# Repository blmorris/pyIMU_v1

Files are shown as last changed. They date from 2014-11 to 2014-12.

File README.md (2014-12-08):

pyskin-IMU
==========

Directory pyIMU contains an IMU skin for the pyboard, providing the MPU9150 accelerometer / gyro / magnetometer and the BMP180 barometric altimeter.

The eagle library pyIMU-03.lbr provides all components and symbols used in this board and schematic.

UPDATE: pyIMU-GPS contains an updated version of the original pyIMU board with a fully integrated GPS receiver module and interface circuitry for monitoring current draw and voltage on a Li-polymer battery pack.

Several device packages have been modified from the originals provided by Sparkfun and the standard Eagle libraries; this is to eliminate design rule check errors and ensure that there is soldermask between the pins on the fine-pitch (0.5mm) components.

The project uses the SSC-EAGLE-2Lyr_v1.0.0.3.dru design rule file; this is a design rule set for 2-layer boards provided by Sunstone Circuits: http://www.sunstone.com/news-resources/cad-tools/eagle

The current project should not generate any errors when run against this DRU file.

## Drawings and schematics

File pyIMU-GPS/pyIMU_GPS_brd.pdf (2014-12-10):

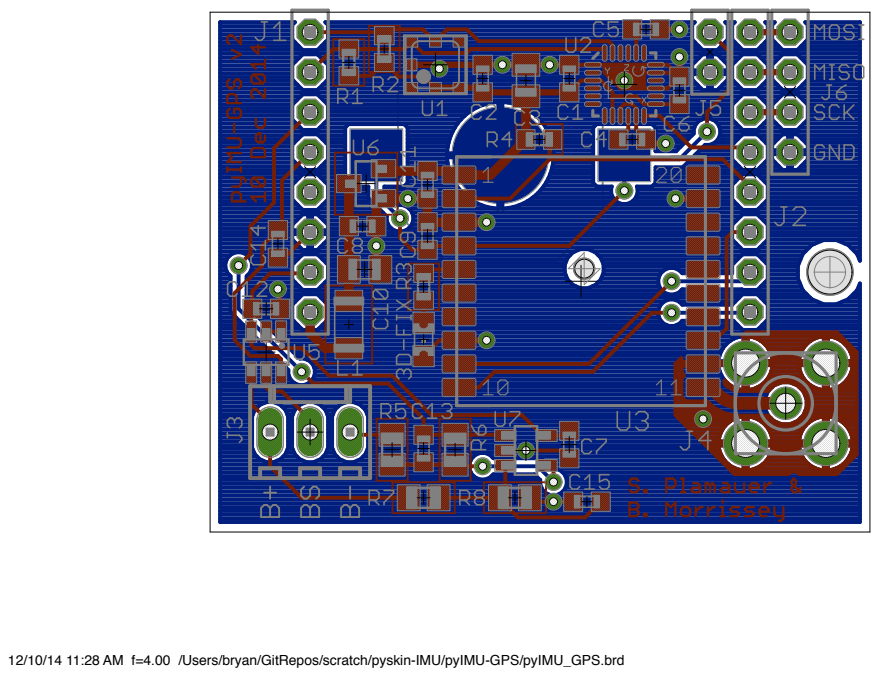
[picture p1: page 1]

12/10/14 11:28 AM f=4.00 /Users/bryan/GitRepos/scratch/pyskin-IMU/pyIMU-GPS/pyIMU_GPS.brd

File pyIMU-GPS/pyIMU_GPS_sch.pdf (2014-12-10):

A

A

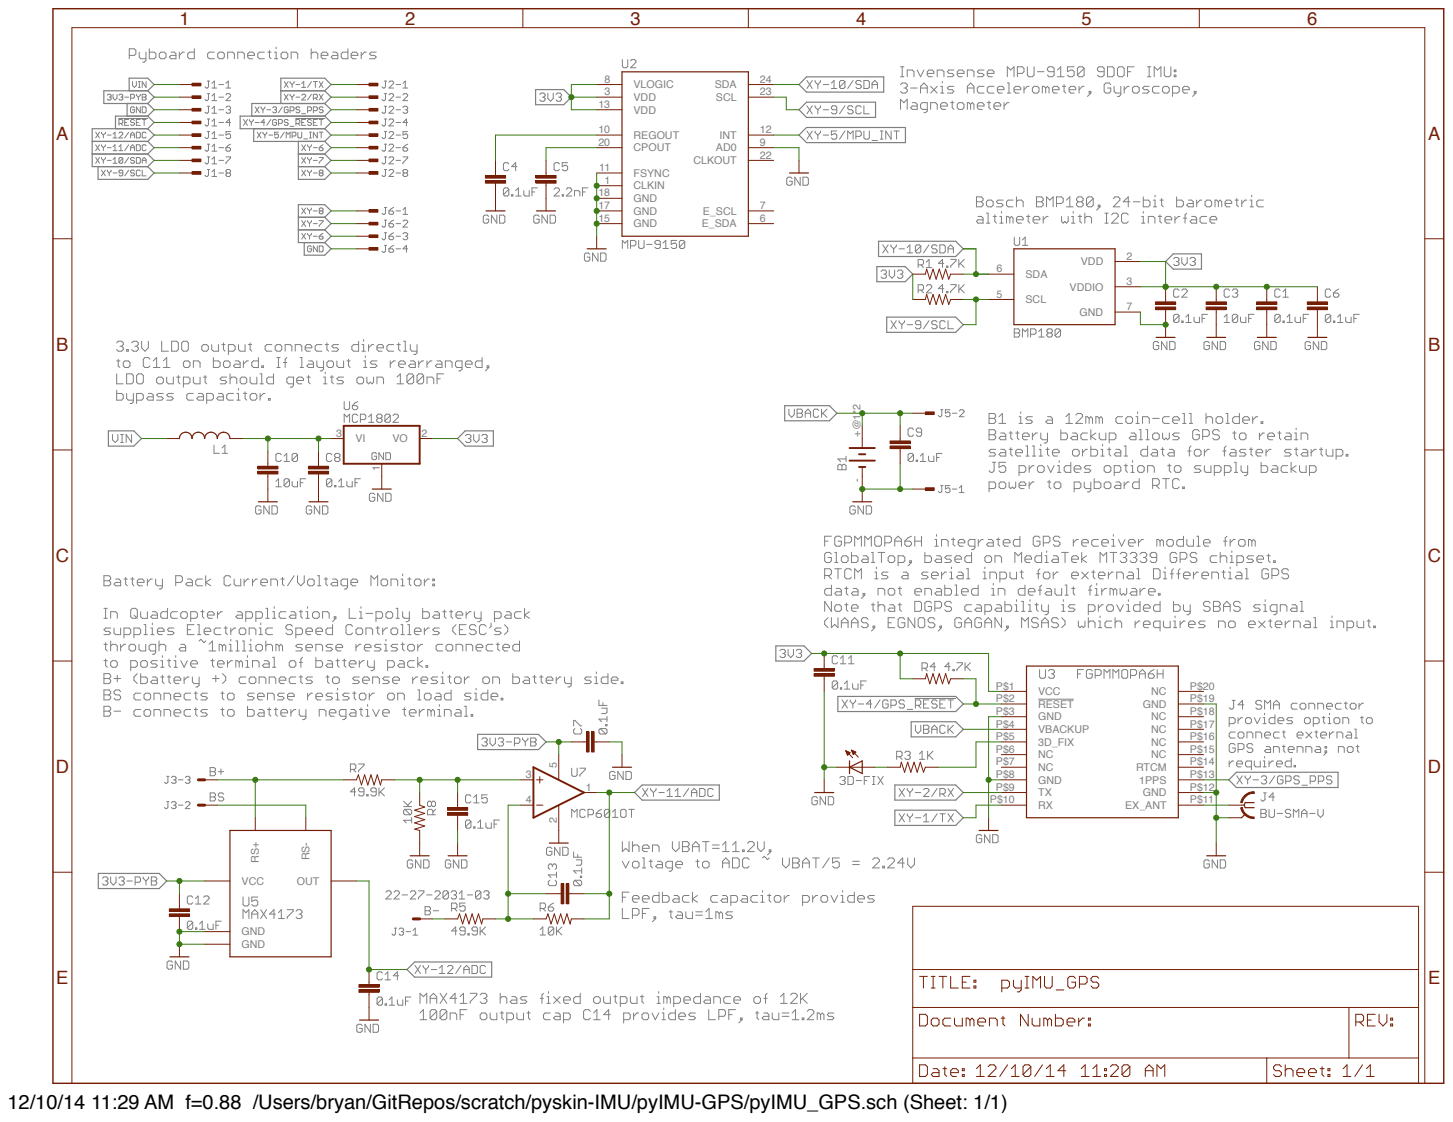
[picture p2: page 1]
GND; 7 SCL 5; SDA 6; VDD; VDDIO; CLKIN 1; CLKOUT; 22 CPOUT 20; E_SCL; E_SDA; FSYNC 11; GND 15; GND 17; GND 18; INT; 12 REGOUT 10; SCL; 23 SDA; VDD 3 VDD 13; VLOGIC 8; RESET P$2; 1PPS; 3D_FIX P$5; EX_ANT; GND P$3; GND P$8; RTCM; VBACKUP P$4; VCC P$1; VCC; OUT

12/10/14 11:29 AM f=0.88 /Users/bryan/GitRepos/scratch/pyskin-IMU/pyIMU-GPS/pyIMU_GPS.sch (Sheet: 1/1)

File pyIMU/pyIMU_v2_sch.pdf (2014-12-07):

1

2

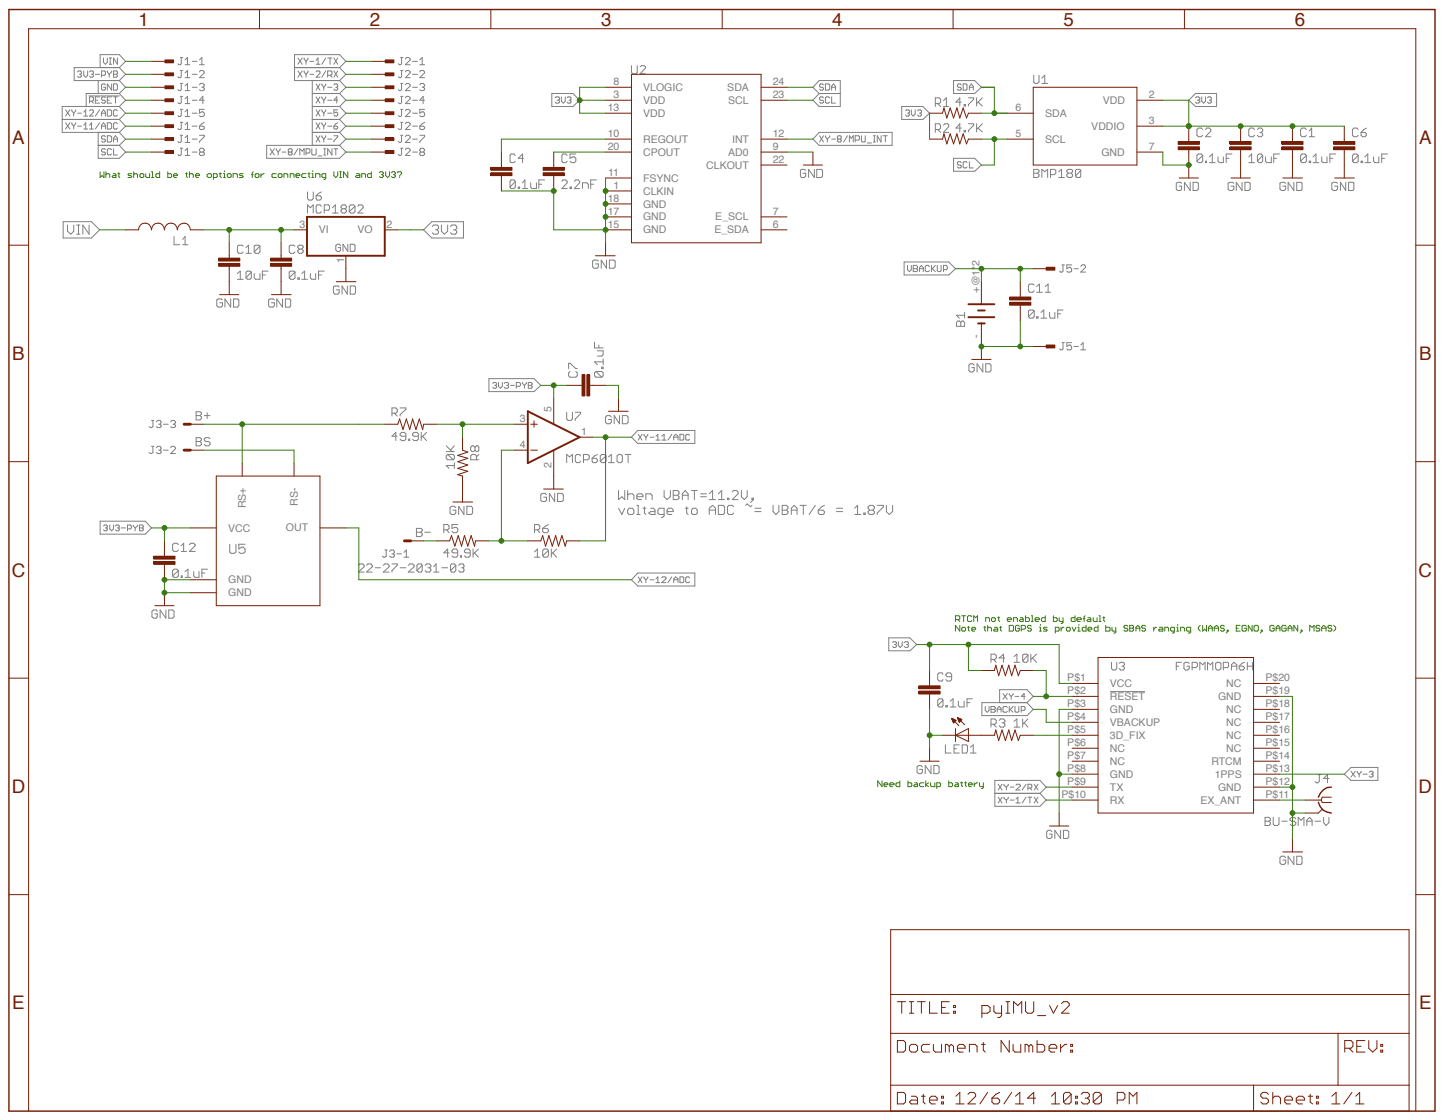
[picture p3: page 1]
GND; 7 SCL; SDA; VDD; VDDIO; CLKIN; CLKOUT; 22 CPOUT 20; E_SCL; E_SDA; FSYNC 11; GND 15; GND 17; GND 18; INT; 12 REGOUT 10; SCL; 23 SDA; 3 VDD 13; VLOGIC; VCC P$1 RESET P$2 GND P$3 VBACKUP P$4 3D_FIX P$5 NC P$6 NC P$7 GND P$8 TX P$9; EX_ANT; P$11 GND; P$12 1PPS; P$13 RTCM; VCC; OUT; ABCDE

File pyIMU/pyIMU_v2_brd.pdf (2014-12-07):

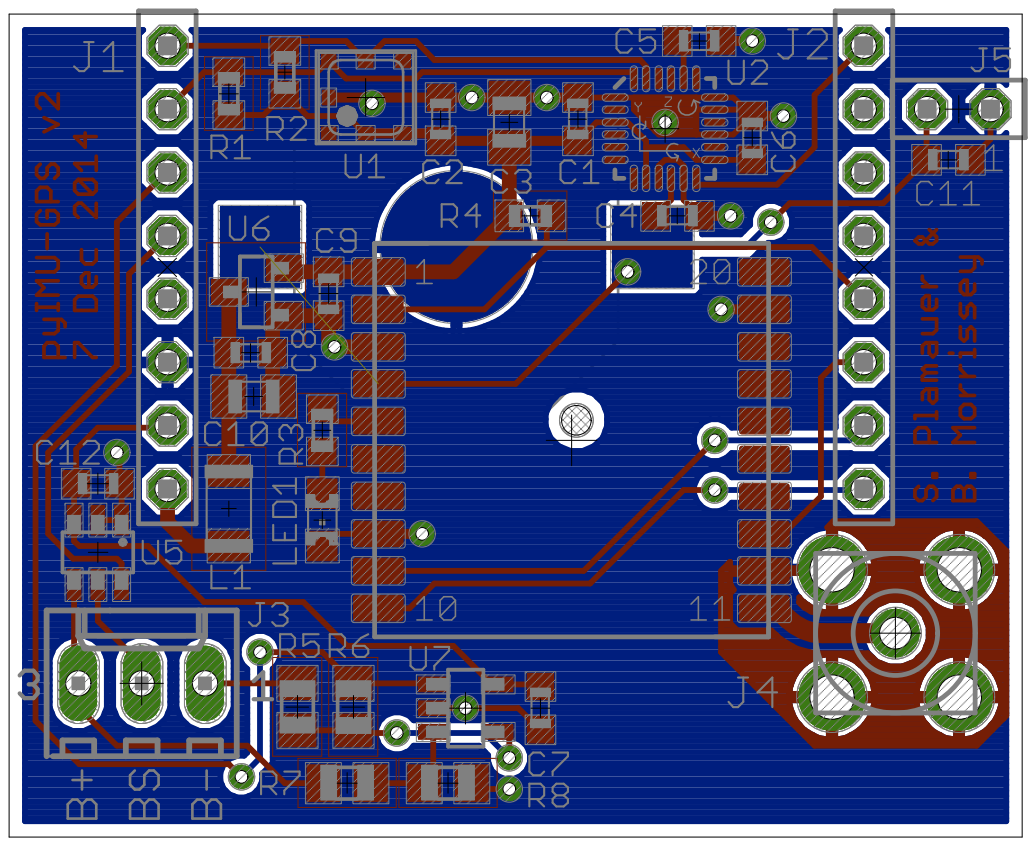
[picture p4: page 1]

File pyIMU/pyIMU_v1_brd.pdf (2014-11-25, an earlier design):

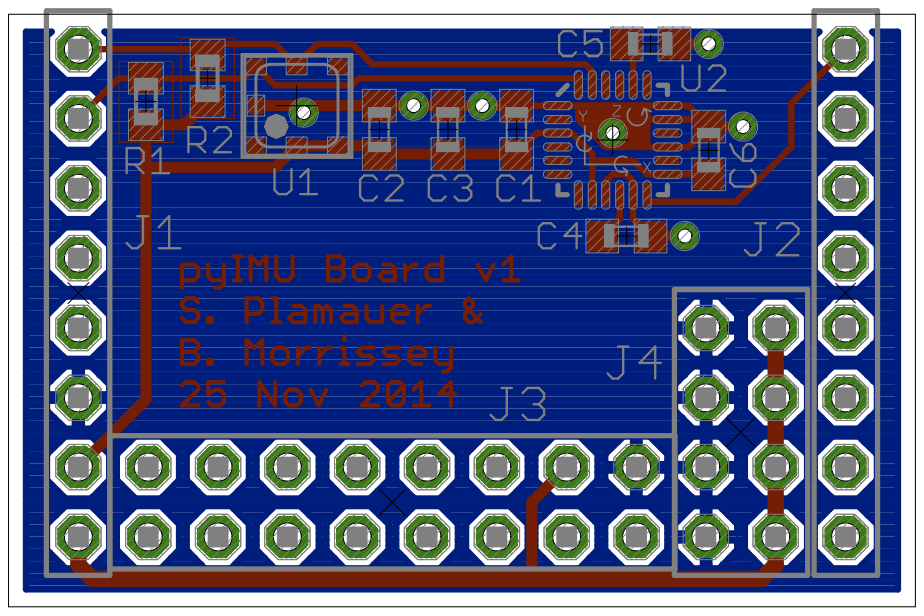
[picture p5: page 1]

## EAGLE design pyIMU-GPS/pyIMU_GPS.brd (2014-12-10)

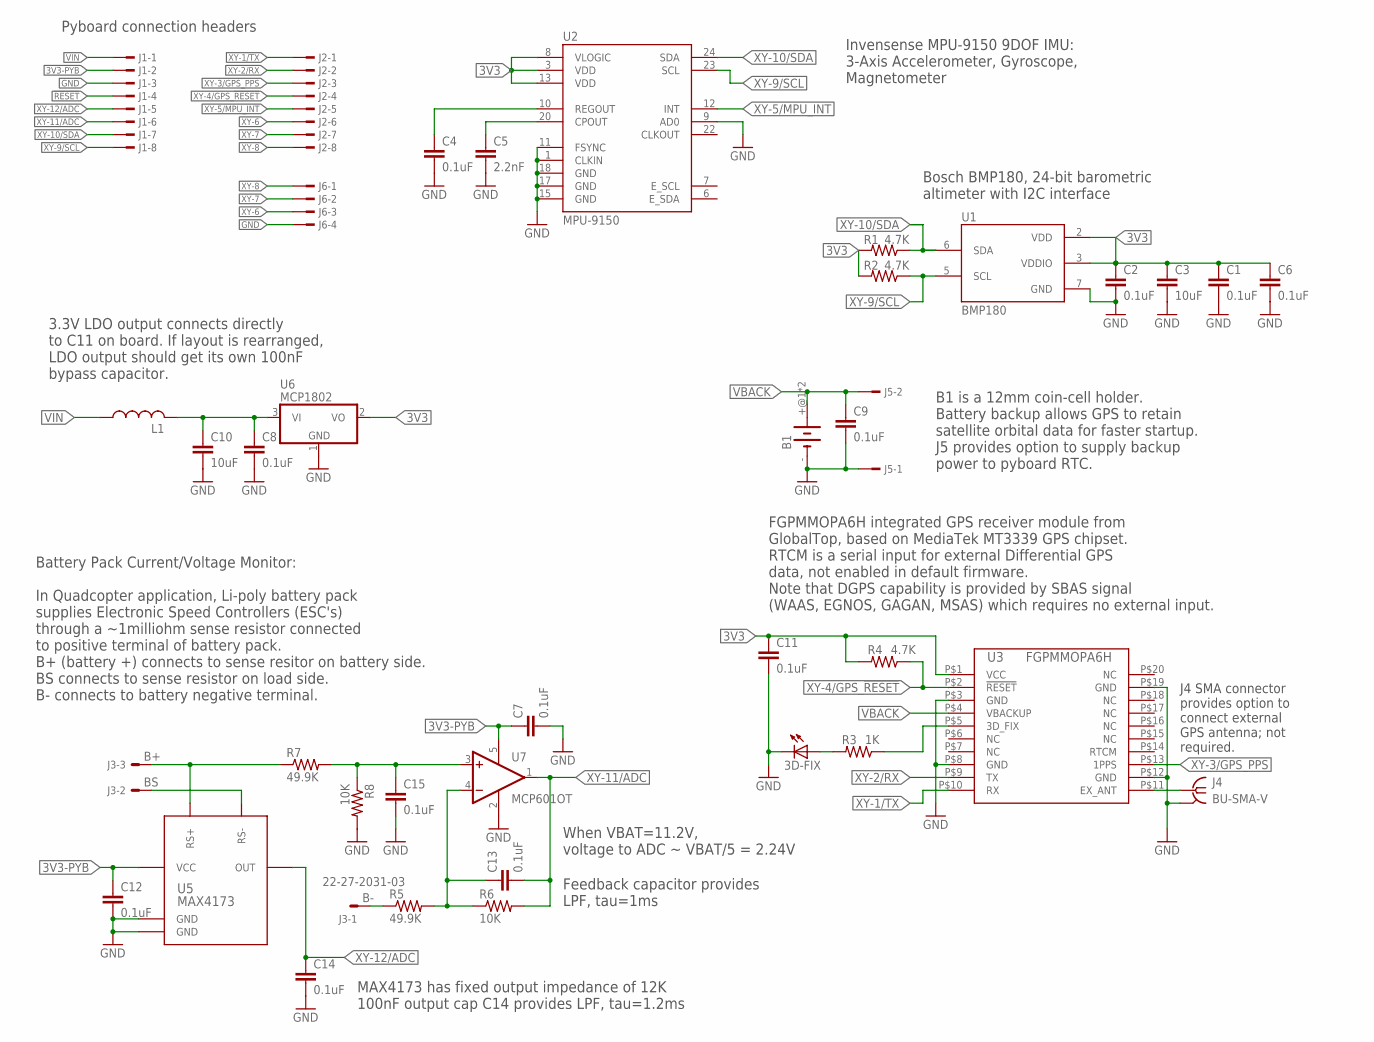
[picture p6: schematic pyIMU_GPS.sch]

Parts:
3D-FIX: LEDCHIPLED_0805; CHIPLED_0805
B1: BATT_HOLDERK3000; KEYSTONE-3000
C1, C2, C4, C6, C7, C8, C9, C11, C12, C13, C14, C15: 0.1uF; C0603K
C3, C10: 10uF; C0805K
C5: 2.2nF; C0603K
J1, J2: TSW-108-02-S-S-MOD
J3: 22-27-2031-03; 6410-03
J4: BU-SMA-V
J5: TSW-102-02-S-S
J6: TSW-104-02-S-S; TSW-104-S-S-MOD
L1: L-USL3216C; L3216C
R1, R2, R4: 4.7K; R0603
R3: 1K; R0603
R5, R7: 49.9K; R0805
R6, R8: 10K; R0805
U1: BMP180
U2: MPU-9150; QFN-24-NP
U3: FGPMMOPA6H
U5: MAX4173; SOT23-6L
U6: MCP1802; SOT23
U7: MCP601OT; SOT23-5

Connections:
3V3: C1.1, C2.1, C3.1, C6.1, C11.1, R1.2, R2.2, R4.2, U1.2 (VDD), U1.3 (VDDIO), U2.3 (VDD), U2.8 (VLOGIC), U2.13 (VDD), U3.P$1 (VCC), U6.2 (VO)
3V3-PYB: C7.1, C12.1, J1.2, U5.3 (VCC), U7.5 (V+)
!RESET: J1.4
B+: J3.3, R7.1, U5.4 (RS+)
B-: J3.1, R5.1
BS: J3.2, U5.5 (RS-)
GND: 3D-FIX.C, B1.-, C1.2, C2.2, C3.2, C4.2, C5.2, C6.2, C7.2, C8.2, C9.2, C10.2, C11.2, C12.2, C14.2, C15.2, J1.3, J4.2, J4.3 (2), J4.4 (2), J4.5 (2), J5.1, J6.4, R8.2, U1.7 (GND), U2.1 (CLKIN), U2.9 (AD0), U2.11 (FSYNC), U2.15 (GND), U2.17 (GND), U2.18 (GND), U3.P$3 (GND), U3.P$8 (GND), U3.P$12 (GND), U3.P$19 (GND), U5.1 (GND), U5.2 (GND), U6.1 (GND), U7.2 (V-)
unnamed: C4.1, U2.10 (REGOUT)
unnamed: C5.1, U2.20 (CPOUT)
unnamed: J4.1, U3.P$11 (EX_ANT)
unnamed: R3.1, U3.P$5 (3D_FIX)
unnamed: 3D-FIX.A, R3.2
unnamed: C15.1, R7.2, R8.1, U7.3 (+IN)
unnamed: C13.1, R5.2, R6.1, U7.4 (-IN)
unnamed: C8.1, C10.1, L1.2, U6.3 (VI)
VBACK: B1.+@1 (+), B1.+@2 (+), C9.1, J5.2, U3.P$4 (VBACKUP)
VIN: J1.1, L1.1
XY-1/TX: J2.1, U3.P$10 (RX)
XY-2/RX: J2.2, U3.P$9 (TX)
XY-3/GPS_PPS: J2.3, U3.P$13 (1PPS)
XY-4/GPS_!RESET: J2.4, R4.1, U3.P$2 (!RESET)
XY-5/MPU_INT: J2.5, U2.12 (INT)
XY-6: J2.6, J6.3
XY-7: J2.7, J6.2
XY-8: J2.8, J6.1
XY-9/SCL: J1.8, R2.1, U1.5 (SCL), U2.23 (SCL)
XY-10/SDA: J1.7, R1.1, U1.6 (SDA), U2.24 (SDA)
XY-11/ADC: C13.2, J1.6, R6.2, U7.1 (OUT)
XY-12/ADC: C14.1, J1.5, U5.6 (OUT)

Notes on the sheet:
FGPMMOPA6H integrated GPS receiver module from GlobalTop, based on MediaTek MT3339 GPS chipset. RTCM is a serial input for external Differential GPS data, not enabled in default firmware. Note that DGPS capability is provided by SBAS signal (WAAS, EGNOS, GAGAN, MSAS) which requires no external inpu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
When VBAT=11.2V, voltage to ADC ~ VBAT/5 = 2.24V
MAX4173 has fixed output impedance of 12K 100nF output cap C14 provides LPF, tau=1.2ms
Feedback capacitor provides LPF, tau=1ms
Battery Pack Current/Voltage Monitor: In Quadcopter application, Li-poly battery pack supplies Electronic Speed Controllers (ESC's) through a ~1milliohm sense resistor connected to positive terminal of battery pack. B+ (battery +) connects to sense resitor on battery side. BS connects to sense resi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
3.3V LDO output connects directly to C11 on board. If layout is rearranged, LDO output should get its own 100nF bypass capacitor.
Pyboard connection headers
B1 is a 12mm coin-cell holder. Battery backup allows GPS to retain satellite orbital data for faster startup. J5 provides option to supply backup power to pyboard RTC.
J4 SMA connector provides option to connect external GPS antenna; not required.
Bosch BMP180, 24-bit barometric altimeter with I2C interface
Invensense MPU-9150 9DOF IMU: 3-Axis Accelerometer, Gyroscope, Magnetometer

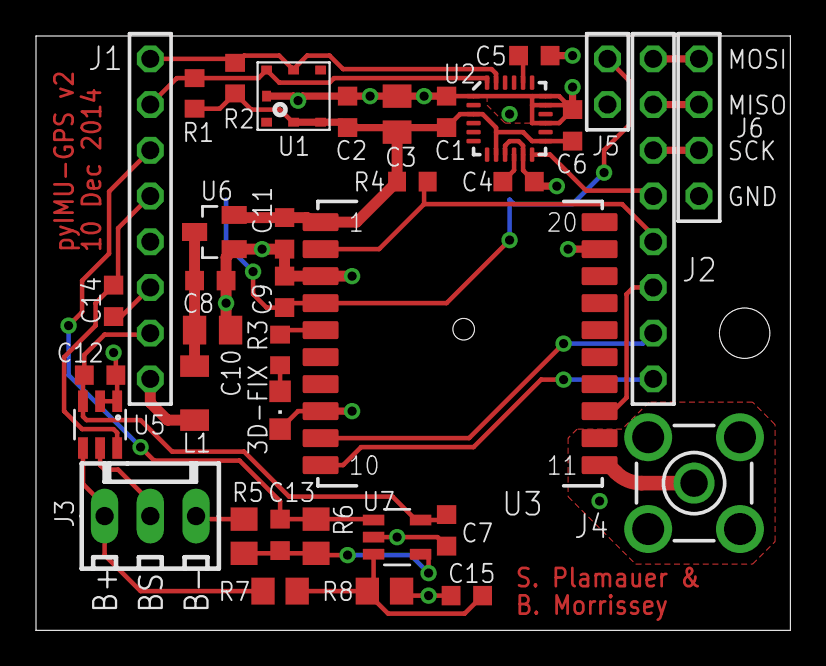
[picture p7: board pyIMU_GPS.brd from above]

Board: 2 copper layers, 41.9 x 33.0 mm, 38 parts (1 on the bottom side), 28 nets.

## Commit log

2014-11-25 Initial commit of pyIMU v1
    [pyIMU.brd, pyIMU.sch, pyIMU_v1.brd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]
2014-12-07 Added PDF's of the board and schematic for version 2 - preliminary desgins, subject to change.
2014-12-08 Commiting design files for GPS enabled version of pyIMU navigation board.
    [pyIMU_GPS.brd, pyIMU_GPS.sch]
2014-12-09 Add mounting hole to board, move MPU_INT from XY8 to XY5, enlarge board slightly, shift GPS module and some other small changes
    [pyIMU_GPS.brd, pyIMU_GPS.sch]
2014-12-10 Fix GPS module package so that all silkscreen markings are in top silkscreen layer Add a via in the SMA antenna ground pour. Move via in VBACK trace outside of battery holder outline to prevent possi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
    [pyIMU_GPS.brd, pyIMU_GPS.sch]
2014-12-10 Update board and schematic PDF's
2014-12-10 Enlarge signal feed hole in center of SMA connector footprint. Available parts probably would not have fit if boards were run with previous footprint.
    [pyIMU_GPS.brd, pyIMU_GPS.sch]
2014-12-10 Add gerber, excellon, and drill/photoplotter files To make a board use top, bot, oln, slk, smb, and smt gerber files along with drd excellon drill file. Other files just provide information about pro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
    [pyIMU_GPS.drl]

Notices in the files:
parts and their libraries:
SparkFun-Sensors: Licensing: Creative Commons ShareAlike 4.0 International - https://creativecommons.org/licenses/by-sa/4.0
